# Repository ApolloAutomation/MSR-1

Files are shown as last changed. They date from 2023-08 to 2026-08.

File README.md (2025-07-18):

# Apollo mmWave CO2 Multisensor Mk1 (MSR-1)



This sensor offers a wide range of functionality for Home Assistant in a very tiny package.

YAML Files:
- MSR-1.yaml: This file is a minimal config. It doesn't have the bluetooth or OTA components. Use this if you are looking to add BLE proxy or BLE tracking.
- MSR-1_BLE.yaml: This file contains BLE proxy code. We use it as an automated test during our build process. But can be an example for adding BLE proxy to your device.
- MSR-1_Factory.yaml: This is the firmware flashed by us on new devices. It contains the components for ESP improve, allowing easy adoption in Home Assistant. When you load the device in ESPHome addon, it will grab the firmware from MSR-1.yaml which no longer has the improve.

Links: \
Discord (Support/feedback/discussion/future products): [https://dsc.gg/ApolloAutomation](https://dsc.gg/ApolloAutomation) \
Shop: [https://apolloautomation.com](https://apolloautomation.com) \
Wiki: [https://wiki.apolloautomation.com](https://wiki.apolloautomation.com/) \
3D Files: [https://www.printables.com/model/564297-apollo-automation-msr-1-mmwave-co2-multisensor-for](https://www.printables.com/model/564297-apollo-automation-msr-1-mmwave-co2-multisensor-for)

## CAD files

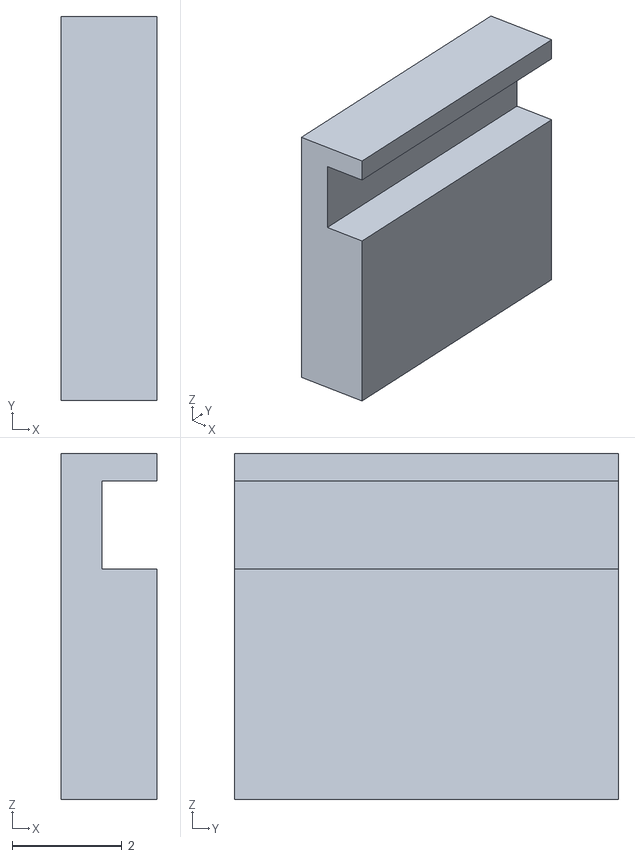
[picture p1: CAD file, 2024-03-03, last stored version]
3D Files/MSR-1_RadarMount_v4.stl
1.75 x 7.00 x 6.30

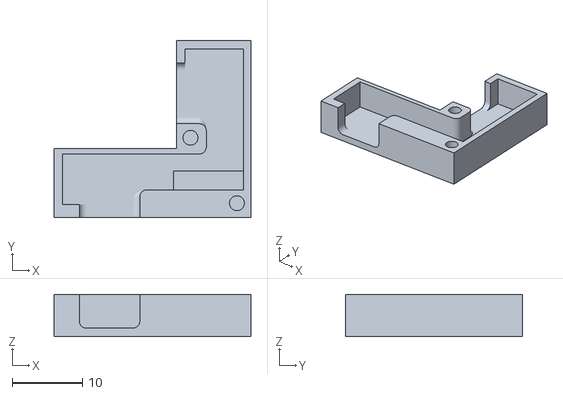
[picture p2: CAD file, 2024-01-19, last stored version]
3D Files/MSR-1_PlugCase_v33.stl
28.0 x 25.1 x 6.00

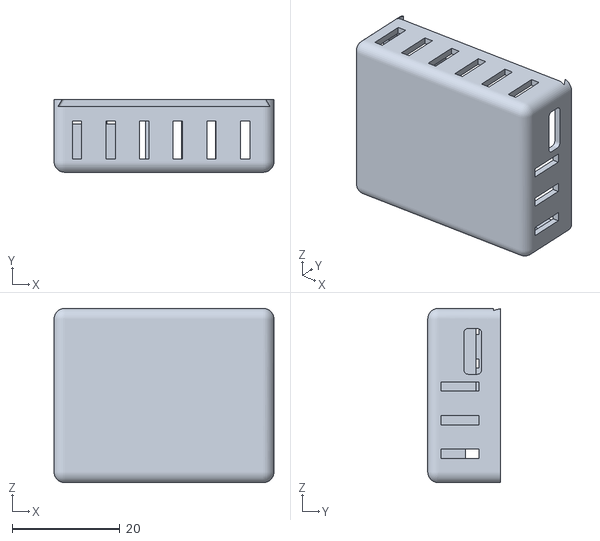
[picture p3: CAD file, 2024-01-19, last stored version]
3D Files/MSR-1_Case_v8.STL
40.9 x 13.5 x 32.4

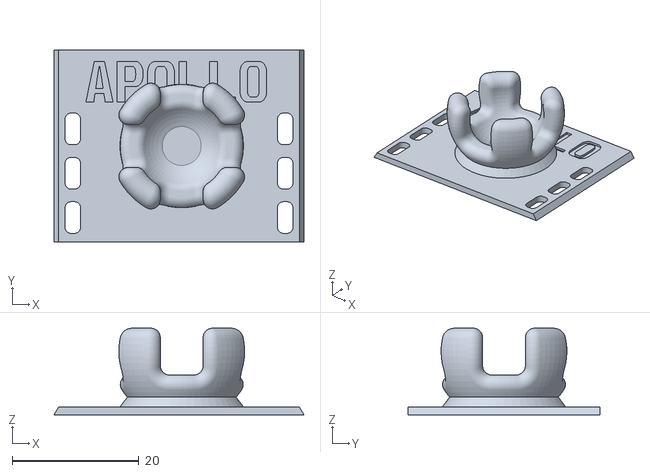
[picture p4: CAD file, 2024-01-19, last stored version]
3D Files/MSR-1_BallMount_Female_v3.STL
39.5 x 30.4 x 13.7

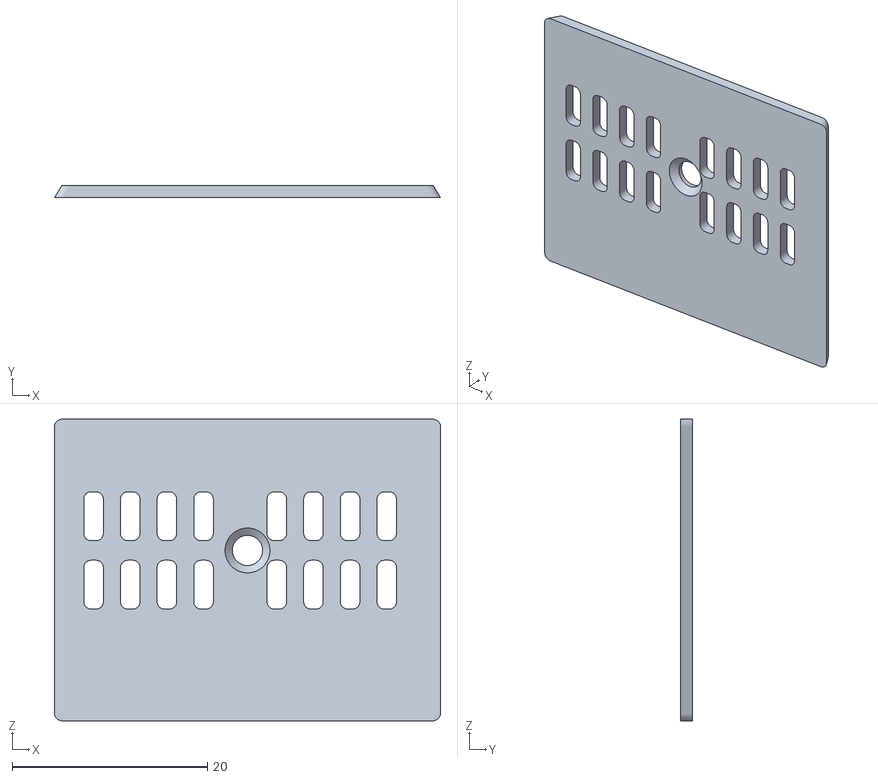
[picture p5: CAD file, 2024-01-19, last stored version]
3D Files/MSR-1_Backplate_v3.STL
39.5 x 1.25 x 30.9

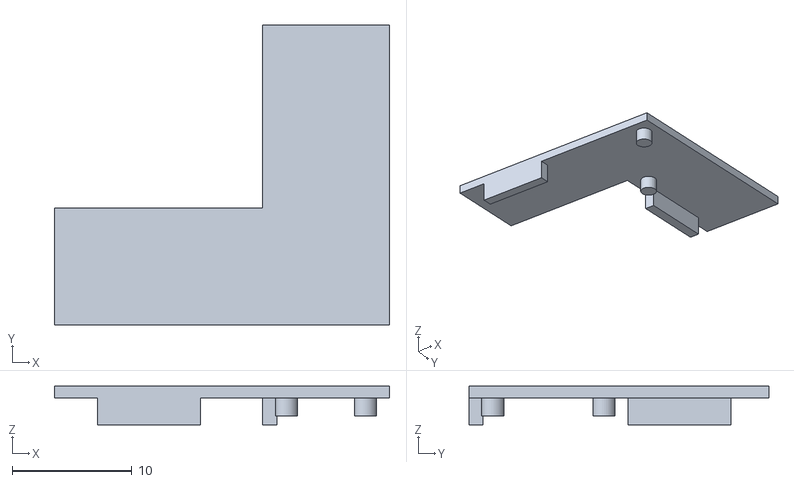
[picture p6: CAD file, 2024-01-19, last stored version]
3D Files/MSR-1_PlugCase_Cap_v33.stl
28.0 x 25.1 x 3.24

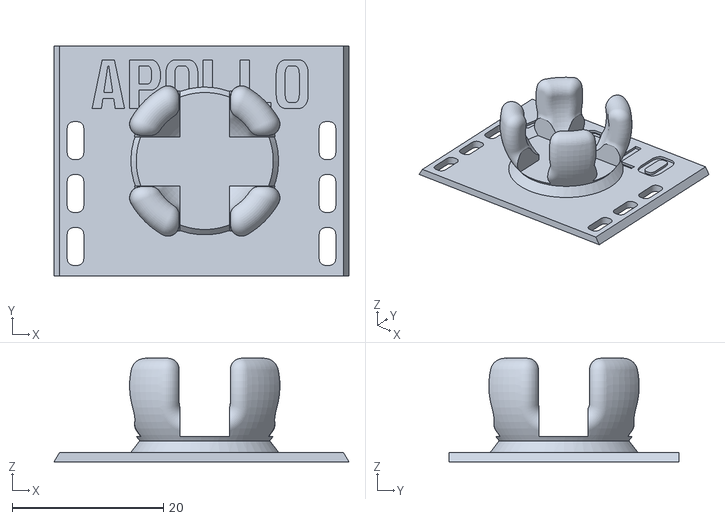
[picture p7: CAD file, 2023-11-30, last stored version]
3D Files/MSR-1_BallMount_Female_More_Rotation.STL
39.0 x 30.4 x 13.7

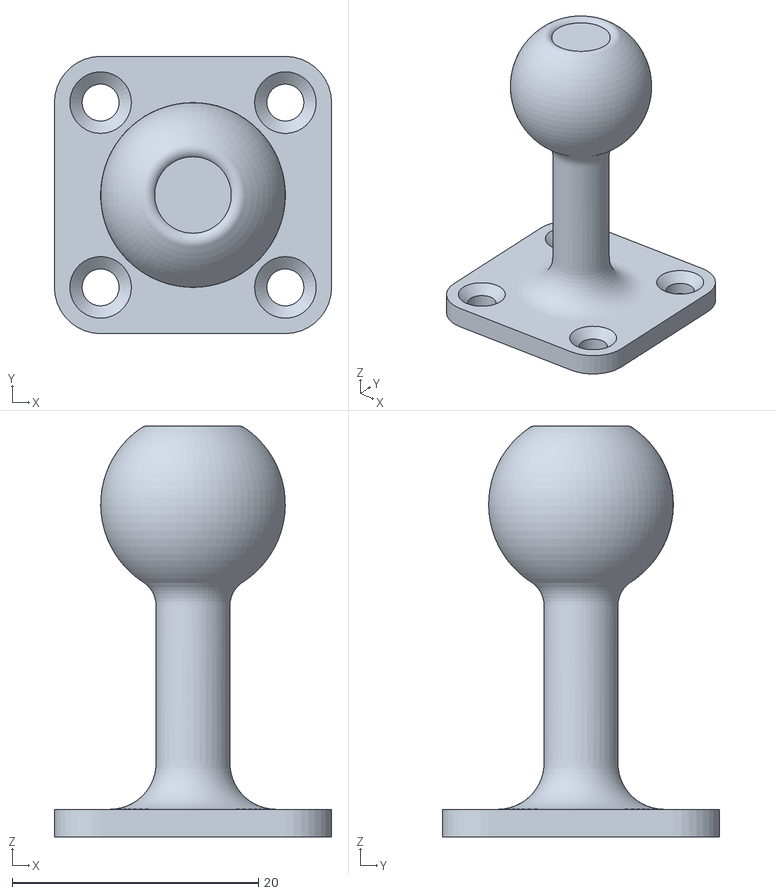
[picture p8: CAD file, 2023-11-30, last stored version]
3D Files/MSR-1_BallMount_Male_Long.STL
22.5 x 22.5 x 33.4

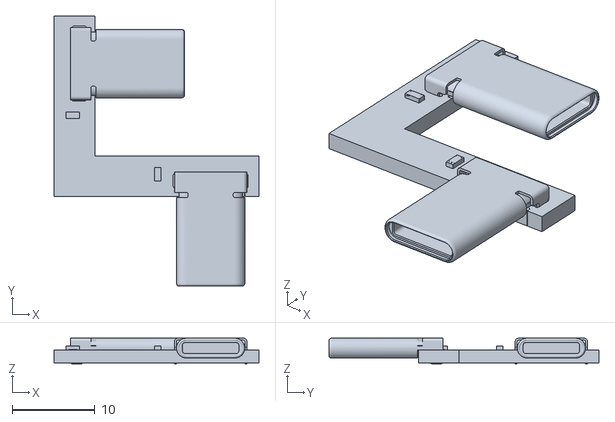
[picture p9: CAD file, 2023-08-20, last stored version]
3D Files/MSR-1_PlugMount.STL
24.7 x 32.6 x 3.10

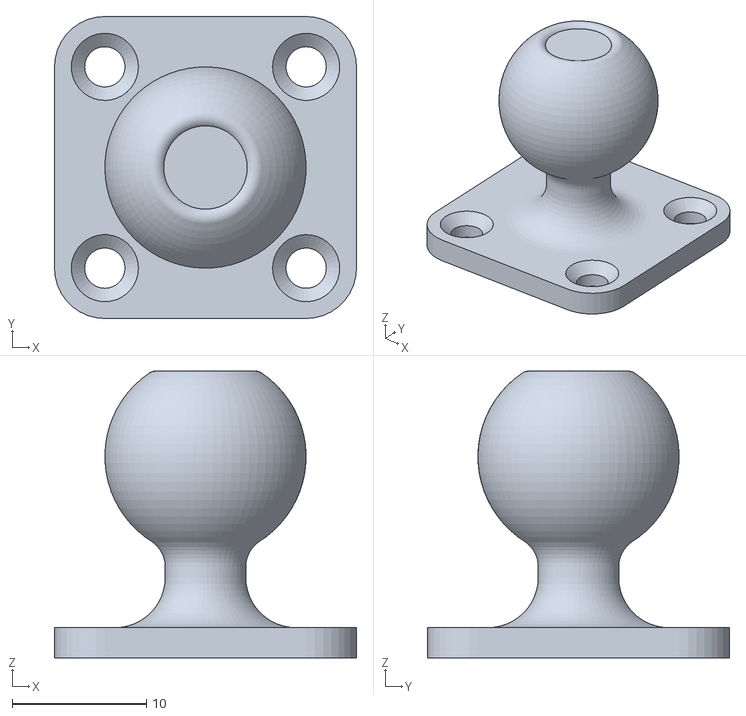
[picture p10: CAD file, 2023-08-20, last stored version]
3D Files/MSR-1_BallMountMale.STL
22.5 x 22.5 x 21.4

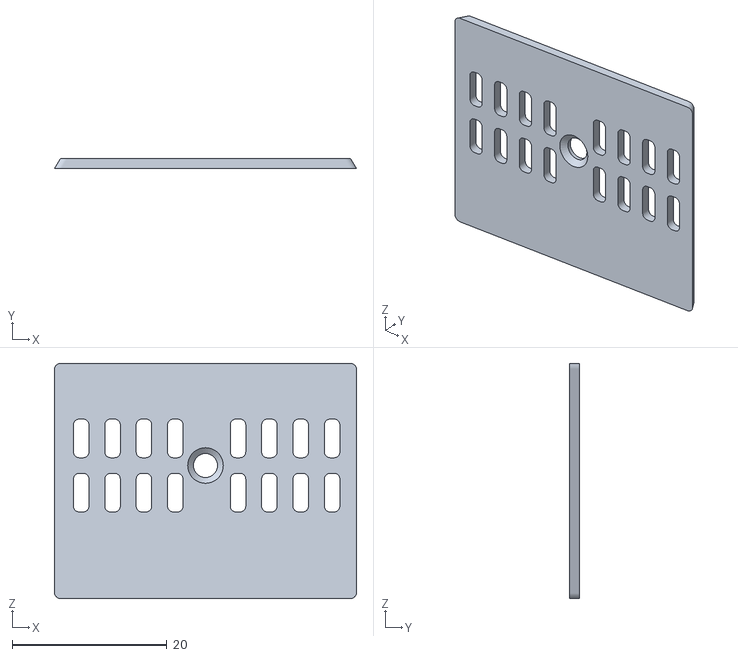
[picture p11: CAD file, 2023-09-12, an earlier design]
3D Files/MSR-1_Backplate.STL
39.0 x 1.25 x 30.4

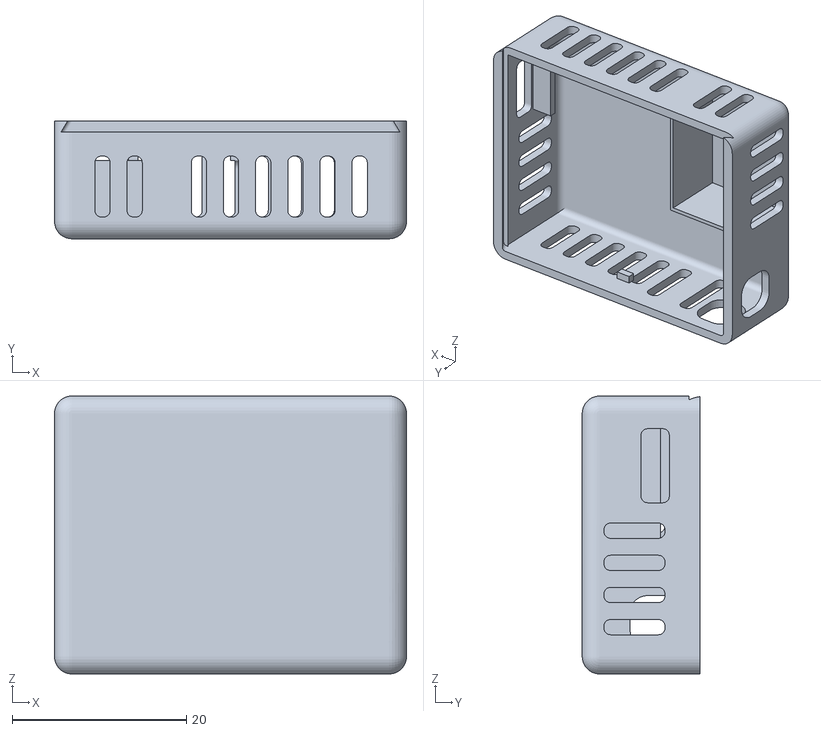
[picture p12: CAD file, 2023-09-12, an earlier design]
3D Files/MSR-1_Case_v6.STL
40.4 x 13.5 x 31.9

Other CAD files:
3D Files/MSR-1_PlugCaseCap.stl
3D Files/MSR-1_BallMountFemale.STL
3D Files/MSR-1_PlugCase.stl

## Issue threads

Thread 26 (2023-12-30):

ambient_light is using native unit of measurement '#' which is not a valid unit for the device class ('illuminance') it is using

morikplay, 2023-12-30:
**Core** 2023.12.4
**Supervisor** 2023.12.0
**Operating System** 11.2
**Frontend** 20231208.2

Getting a HA startup warning  after installation of 1st MSR-1

```
Logger: homeassistant.components.sensor
Source: components/sensor/__init__.py:691
Integration: Sensor (documentation, issues)
First occurred: 11:09:24 PM (3 occurrences)
Last logged: 11:09:24 PM

    Entity sensor.sensor_presence_mbr_ltr390_ambient_light (<class 'homeassistant.components.esphome.sensor.EsphomeSensor'>) is using native unit of measurement '#' which is not a valid unit for the device class ('illuminance') it is using; expected one of ['lx']; Please update your configuration if your entity is manually configured, otherwise create a bug report at https://github.com/home-assistant/core/issues?q=is%3Aopen+is%3Aissue+label%3A%22integration%3A+esphome%22
    Entity sensor.sensor_presence_mbr_ltr390_uv_index (<class 'homeassistant.components.esphome.sensor.EsphomeSensor'>) is using native unit of measurement 'UVI' which is not a valid unit for the device class ('illuminance') it is using; expected one of ['lx']; Please update your configuration if your entity is manually configured, otherwise create a bug report at https://github.com/home-assistant/core/issues?q=is%3Aopen+is%3Aissue+label%3A%22integration%3A+esphome%22
    Entity sensor.sensor_presence_mbr_ltr390_uv (<class 'homeassistant.components.esphome.sensor.EsphomeSensor'>) is using native unit of measurement '#' which is not a valid unit for the device class ('illuminance') it is using; expected one of ['lx']; Please update your configuration if your entity is manually configured, otherwise create a bug report at https://github.com/home-assistant/core/issues?q=is%3Aopen+is%3Aissue+label%3A%22integration%3A+esphome%22
```

relevant ESPHome config
```
substitutions:
  name: sensor-presence-mbr
  friendly_name: sensor-presence-mbr
packages:
  Apollo.Presence_Sensor: github://ApolloAutomation/MSR-1/Integrations/ESPHome/MSR-1.yaml
esphome:
  name: ${name}
  name_add_mac_suffix: false
  friendly_name: ${friendly_name}
```

Nunjafush, 2024-02-27:
Same problem for me with HA warnings at startup. Been happening for multiple versions of Core, OS and ESPHome since installed in early January 2024:

Core 2024.2.2
Supervisor 2024.02.0
Operating System 12.0
Frontend 20240207.1
ESPHome 2024.2.0

Log Details:

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

Relevant ESPHome config:

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

kuzaxak, 2024-03-20:
I think it happens because wrong sensor got exported. I see in ESPHome UI 3, but in HA only 2 of them.
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

Nunjafush, 2024-03-21:
The settings for LTR390 are apparently not defined in the Apollo MSR1 configuration but just read from the LTR390 definition in ESPHome.

In ESPHome, LTR390 had a device class of "illuminance" but yesterday's ESPHome 2024.3.0 update has now set it to "empty".
Since the update, I no longer get the errors in my log.

axx4one, 2024-03-25:
> In ESPHome, LTR390 had a device class of "illuminance" but yesterday's ESPHome 2024.3.0 update has now set it to "empty". Since the update, I no longer get the errors in my log.

I can confirm that the Light lux sensor is now gone (not just disabled) after updating to ESPHome 2024.3.0. That‘s not a fix but rather a new issue. My automations using the MSR-1 lux light sensor aren’t working anymore. The ambient light sensor cannot be used as well (e.g. in the Sensor Light blueprint from @Blacky).

neilmartin83, 2024-03-25:
Looks like we only have the `ambient_light` sensor for the LTR390 platform in https://github.com/ApolloAutomation/MSR-1/blob/789634b6d1ee802307523d167a15dbed01423654/Integrations/ESPHome/MSR-1.yaml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

I'd suggest replacing the `ambient_light` sensor with just `light` as not sure if we need it:

> ambient_light (Optional): [Sensor](https://esphome.io/components/sensor/#config-sensor) counts for the Ambient light sensor (#). All options from Sensor.

```
    light:
      name: "LTR390 Light"
      id: ltr390light
```

If you add the below to your own configuration YAML in the ESPHome addon and reflash, it will expose the correct sensor (I also set the `update_interval` every 5 seconds as it's much more useful for my use case):

```
sensor:
  - platform: ltr390
    id: !extend ltr_390
    light:
      name: "LTR390 Light"
      id: ltr390light
    update_interval: 5s
```

Bunton33, 2024-03-26:
We appreciate you sending us this update. I will talk with our technical
lead and see about implementing it. Please let us know if you need anything
else.

Best,
Justin Bunton
Apollo Automation

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

TrevorSchirmer, 2024-03-26:
Apologies for the mistake. When we reduce the firmware size I removed it on accident when I meant to remove ambient_light.

The PR is merged and should let you update from the ESPHome add-on in about a day.

Also sorry for not seeing the new comments on this issue, I'll figure out how to get better notifications from these. Feel free to tag me in the future if we break something.

Thanks for your all's help!

Thanks,
Trevor

cowboyrushforth, 2024-04-03:
Hey there, not sure if this is the best place to comment on this light sensor issue, but for me, I have two different MSR-1 units.

After this firmware update both show the light in HA - however, one unit is always "stuck" with whatever the light senses on bootup and never changes, the other one changes as the light level in the room changes.  For example if I shine a flashlight at it, it will correctly go way up to 120 lx, or if I turn off all the lights in the room it will go to 0 or 1 lx.

The other one works fine with regards to proximity and radar, but the light value again just stays at whatever it detects on bootup.  Is there a way to somehow hard reset that sensor?  I have tried reinstalling the firmware and power-cycling it but nothing seems to work.

Thanks!

TrevorSchirmer, 2024-04-03:
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

Hello,

Yes that seems to be some problem. I'm worried about notifying everyone on this thread with some troubleshooting back and forth. Can we move this to a new issue on GitHub? Or feel free to jump into our support channel on Discord and we can walk you through some steps and try to get it resolved. We can try to change the update interval, and look at the sensor's built in portal to see if it is a HA/network problem or a hardware problem.

Discord: https://discord.gg/mMNgQPyF94

Thanks!
-Trevor

Closed 2024-03-26.

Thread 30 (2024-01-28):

MSR-1 crashes/hangs several times a day

allthesebugsv2, 2024-01-28:
Hey there,

the sensor is unfortunately hanging several times a day. This goes hand in hand with a sharp increase in the esp temperature:

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

Usually, it restarts then at some point after becoming unavailable. But sometimes I even have to re-plug its power to make it available again. I have not noticed a pattern regarding this.

Firmware: 2023.11.6 (Dec 8 2023, 16:57:05)
Hardware: 23.12081

If there is a firmware update available, then I don't see where. I do not use ESPHome (only Home Assistant inside Docker), so I cannot follow this guide: https://wiki.apolloautomation.cloud/books/general/page/updating-firmware

Bunton33, 2024-01-28:
Hello,

Sorry to hear about the esp shutting down. There is a newer firmware
version. Can you try following this wiki guide?
https://wiki.apolloautomation.cloud/books/msr-1/page/manually-uploading-code-through-esphome

It uses ESPHome web so you shouldn't need the addon. Let us know how it
goes.

Thanks,
Justin Bunton
Apollo Automation

On Sun, Jan 28, 2024, 1:48 PM allthesebugsv2 ***@***.***>
wrote:

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

allthesebugsv2, 2024-01-30:
Thanks, I have managed to update the firmware and am now running
Firmware: 2023.11.6 (Jan 10 2024, 23:20:18)
Hardware: 24.1.10.1

However, even after updating I have had 3 crashes in the last 24h:
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

Bunton33, 2024-01-30:
Hello,

Glad to hear that you were able to update the firmware. We are not exactly
sure what's causing the device to crash though, so we will exchange it for
a new one. What is your order number?

Best,
Justin
Apollo Automation

On Tue, Jan 30, 2024, 7:47 AM allthesebugsv2 ***@***.***>
wrote:

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

allthesebugsv2, 2024-01-30:
That is extremely kind, I'll got back to you via mail

Closed 2024-01-30.

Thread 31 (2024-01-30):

Variables For Update Frequency

TrevorSchirmer, 2024-01-30:

KidA001, 2024-02-03:
Hey, thanks for creating this feature request. I'll paste my details from discord here:

One thing I would love is to change the update interval of the sensors as a variable (both for the distance sensor and air sensor). In order to do this currently I'd have to copy the ESPHome code and manually change it in there, which then means I have to manually maintain that code now and copy any updates manually.

Some of these sensors update very frequently which can be nice in some use cases, but ends up with a lot of granularity (and DB Writes) that I don't need. I'd love to be able to set the update interval with some kind of input variable. Much appreciated!

TrevorSchirmer, 2024-02-21:
@KidA001 Thank you very much for the addition here. I went back and forth but thought adding entities for all the sensors update frequency would clutter a little and confuse some.

Instead I made sure they all had IDs, this will allow you or anyone to !extend them and change the frequency. For example see attached, I changed the ltr390's update frequency from the default 60s to 5s. Please let me know if you have any questions or suggestions how to better handle this.

`sensor:
  - platform: ltr390
    id: !extend ltr_390
    update_interval: 5s`

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

-Trevor

Closed 2024-02-21.

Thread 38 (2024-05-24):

Wi-Fi power_save_mode set to “none”

neilmartin83, 2024-05-24:
Heya - this is more of a query than a problem.

I was wondering what the reasoning was for setting `power_save_mode: none`? Did you observe issues with the sensor or connectivity which needed this?

I tend to set this to `light` on all my ESP32 devices (it’s the default if not configured) and notice significantly lower running temps of the chip itself with no perceptible change of stability or performance.

Cheers! Loving this sensor.

Bunton33, 2024-05-24:
Neil,

We appreciate your support and thanks for reaching out! We debated this and decided to go with none because we didn't want people to experience any connectivity issues. If users talked about the heat buildup then we would suggests them to use light to decrease the heat. We haven't heard of or experienced any connectivity issues on any setting. The best part is it's all open source and the community can do whatever they want. Thanks again for the kind words. We are always available if you need anything.

Best,
Justin Bunton
Apollo Automation
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

TrevorSchirmer, 2024-05-25:
@neilmartin83 If you'd like help setting it to low power mode let us know and we can post a wiki article for it.
-Trevor

neilmartin83, 2024-05-25:
Cheers @TrevorSchirmer - I've already set it up on my MSR-1, as well as enabling Bluetooth proxy and disabling the web server, but think a KB would be great for others! It's been rock solid for weeks.

Thank you.

bharvey88, 2024-06-20:
solved wiki is now here https://wiki.apolloautomation.com/books/general/page/adjusting-wifi-power-save

Closed 2024-07-03.

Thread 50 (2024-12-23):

cannot change wifi

tung256, 2024-12-23:
anyone know how i can change my wifi?

as of now, everything works fine with my tmvc SSID.

i added tmvd to my house and hence this is my config.
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

when i click on Install Wirelessly, i get instant error. i also tried Update but same error :
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

when i tried to use ESPhome to compile this yaml  https://github.com/ApolloAutomation/MSR-1/blob/main/Integrations/ESPHome/MSR-1.yaml    i also get a bunch of errors:
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

can someone please help?

TrevorSchirmer, 2025-01-04:
Hello,

Sorry for the delay. It looks like your ESPHome addon version/integration might be too old? Can you update that and confirm if it is still happening.

Thanks,
Trevor

Closed 2025-02-20.

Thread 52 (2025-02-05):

MSR-1_BLE ESPHome install error - light.neopixelbus

stumain, 2025-02-05:
Trying to use the BLE enabled edition of the firmware for an MSR-1 but receive an error for light.neopixelbus in core.yaml.  Documentation on https://esphome.io/components/light/neopixelbus.html suggests this feature is not availble when using ESP-IDF.

Tried removing the use of the ESP-IDF and the firmware compile and install works.  Will wait and see how stable the MSR-1 using this.

Could be documentation update to remove the use of ESP-IDF or removal of neopixel functions if ESP-IDF is still required for another reason?

BTW, Awesome little sensors!!

neilmartin83, 2025-02-06:
If you are using ESP-IDF add this to your config in the ESPHome Builder to get the light working. esp32_rmt_led_strip is a replacement for neopixelbus.

```
light:
    platform: esp32_rmt_led_strip
    id: rgb_light
    name: RGB Light
    pin: GPIO3
    num_leds: 1
    rmt_channel: 0
    rgb_order: GRB
    chipset: ws2812
```

TrevorSchirmer, 2025-02-20:
Hi, apologies for the delay. There was a bug in the bluetooth yaml file we have but it wasn't the one you listed. I just merged a fix, could you give it a shot again?

Also could you link to the documentation that showed switching to ESP-IDF? I couldn't find it.

Thanks

TrevorSchirmer, 2025-07-18:
We just merged the firmware change to correct this and add new MSR-2 functionality to the MSR-1. Thanks again!

Closed 2025-03-27.

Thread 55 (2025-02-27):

Migrate from arduino framework to esp-idf

hajar97, 2025-02-27:
MSR-2 is already based on esp-idf framework. However, MSR-1 continues to stick to arduino. Since arduino has extra separation layers it can make the code run slower and device be more likely overloaded. ESPHome now recommends use of esp-idf framework as the main one. Can we migrate MSR-1 to this framework that is lighter and better supported in ESPHome?

RN-Say, 2025-07-18:
As of ESPHome version (2025.7.1) I am getting the following error that appears to be related to the arduino platform when attempting to install:

`INFO ESPHome 2025.7.1
INFO Reading configuration /config/esphome/apollo-msr-1-06dbc0.yaml...
INFO Updating https://github.com/ApolloAutomation/MSR-1@main
INFO Generating C++ source...
INFO Compiling app...
Processing guest-bath-multisensor (board: esp32-c3-devkitm-1; framework: arduino; platform: https://github.com/pioarduino/platform-espressif32/releases/download/53.03.13/platform-espressif32.zip)
--------------------------------------------------------------------------------
Library Manager: Installing SPI
INFO Installing SPI
HARDWARE: ESP32C3 160MHz, 320KB RAM, 4MB Flash
 - framework-arduinoespressif32 @ 3.1.3
 - framework-arduinoespressif32-libs @ 5.3.0+sha.489d7a2b3a
 - tool-esptoolpy @ 4.8.6
 - tool-mklittlefs @ 3.2.0
 - tool-riscv32-esp-elf-gdb @ 14.2.0+20240403
 - tool-xtensa-esp-elf-gdb @ 14.2.0+20240403
 - toolchain-riscv32-esp @ 13.2.0+20240530
Dependency Graph
|-- Networking @ 3.1.3
|-- AsyncTCP @ 3.4.5
|-- WiFi @ 3.1.3
|-- FS @ 3.1.3
|-- Update @ 3.1.3
|-- ESPAsyncWebServer @ 3.7.10
|-- ESP32 Async UDP @ 3.1.3
|-- DNSServer @ 3.1.3
|-- ESPmDNS @ 3.1.3
|-- Wire @ 3.1.3
|-- ArduinoJson @ 7.4.2
|-- NeoPixelBus @ 2.8.0
|-- noise-c @ 0.1.10
RAM:   [==        ]  19.0% (used 62244 bytes from 327680 bytes)
Flash: [==========]  114.1% (used 2094434 bytes from 1835008 bytes)
Error: The program size (2094434 bytes) is greater than maximum allowed (1835008 bytes)

💡 TIP: Your ESP32 with Arduino framework has run out of flash space.

To fix this, switch to the ESP-IDF framework which is more memory efficient:

1. In your YAML configuration, modify the framework section:

   esp32:
     framework:
       type: esp-idf

2. Clean build files and compile again

Note: ESP-IDF uses less flash space and provides better performance.
Some Arduino-specific libraries may need alternatives.

*** [checkprogsize] Explicit exit, status 1
========================== [FAILED] Took 4.62 seconds ==========================`

Closed 2025-07-18.

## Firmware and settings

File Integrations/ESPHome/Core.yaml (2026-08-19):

substitutions:
  version:  "26.8.19.1"
  device_description: ${name} made by Apollo Automation - version ${version}.
  # Default OTA password. Override in your device YAML by re-declaring
  # `substitutions: { ota_password: !secret <name>_ota_password }` so each
  # device on your network uses a unique secret instead of the shared default.
  ota_password: "apolloautomation"
  # Manifest URL bases. Stable = GitHub Pages (main branch builds).
  # Beta = rolling "beta" pre-release assets (beta branch builds).
  stable_manifest_base: "https://apolloautomation.github.io/MSR-1"
  beta_manifest_base: "https://github.com/ApolloAutomation/MSR-1/releases/download/beta-fw"
  # Per-variant OTA manifest URLs. Core defaults to the unified (standard)
  # image; MSR-1_BLE.yaml overrides these so legacy BLE devices stay on the
  # firmware-ble manifest.
  ota_stable_manifest: "${stable_manifest_base}/firmware/manifest.json"
  ota_beta_manifest: "${beta_manifest_base}/manifest-standard.json"

  # Bluetooth Proxy switch state on a device with no stored preference yet
  # (first boot after this switch was added, or after a factory reset). The
  # unified image ships the proxy off; MSR-1_BLE.yaml overrides this to ON so
  # legacy BLE devices keep proxying instead of going quiet after an update.
  bluetooth_proxy_restore_mode: RESTORE_DEFAULT_OFF

esphome:
  # List form so package merging concatenates with each variant's own on_boot
  # entries (mapping form would be replaced by the variant's block instead).
  on_boot:
    - priority: -100
      then:
        - script.execute: apply_ota_source
    # Re-apply the Bluetooth Proxy switch after all components set up, so BLE
    # scanning matches the switch state restored from flash.
    - priority: -300
      then:
        - if:
            condition:
              switch.is_on: bluetooth_proxy_switch
            then:
              - esp32_ble_tracker.start_scan:
                  continuous: true
            else:
              - esp32_ble_tracker.stop_scan:

esp32:
  variant: esp32c3
  flash_size: 4MB
  framework:
    type: esp-idf

esp32_ble_tracker:
  id: ble_tracker
  scan_parameters:
    continuous: true

bluetooth_proxy:

captive_portal:

web_server:
  port: 80
  version: 3

http_request:
  verify_ssl: true
  # GitHub release-asset downloads answer with a redirect carrying a
  # ~3.6 KB Content-Security-Policy header; each header line must fit
  # this buffer or the request fails with "HTTP_CLIENT: Out of buffer".
  buffer_size_rx: 5120
  # The redirect target is a signed URL with a ~850-char query string; the
  # follow-up request line must fit the TX buffer or esp_http_client_open
  # fails with "Out of buffer" before sending anything.
  buffer_size_tx: 2048

api:
  encryption:
  on_client_connected:
    - delay: 1s
    - light.turn_off: rgb_light
    - lambda: 'id(cycleCounter) = 30;'
  actions:
    - action: play_buzzer
      variables:
        song_str: string
      then:
        - rtttl.play:
            rtttl: !lambda 'return song_str;'

    #Co2 Calibration Action
    - action: calibrate_co2_value
      variables:
        co2_ppm: float
      then:
        - scd4x.perform_forced_calibration:
            value: !lambda 'return co2_ppm;'
            id: scd40

    #Setting HLK Password
    - action: set_ld2410_bluetooth_password
      variables:
        password: string
      then:
        - bluetooth_password.set:
            id: ld2410_radar
            password: !lambda 'return password;'

globals:
  - id: cycleCounter
    type: int
    restore_value: no
    initial_value: '0'
  - id: button_press_timestamp
    restore_value: no
    type: uint32_t
    initial_value: '0'
  - id: ltr390_last_update
    restore_value: no
    type: uint32_t
    initial_value: '0'

i2c:
  sda: GPIO1
  scl: GPIO0
  id: bus_a

uart:
  tx_pin: GPIO21
  rx_pin: GPIO20
  baud_rate: 256000
  parity: NONE
  stop_bits: 1
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

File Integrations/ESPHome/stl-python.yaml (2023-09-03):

#Define Project
substitutions:
  name: apollo-msr-1
  version:  23-08-26-1
  device_description: ${name} made by ApolloAutomation - version ${version}.
  
esphome:
  name: "${name}"
  friendly_name: Apollo Multisensor Mk1 (MSR-1)
  comment: Apollo Multisensor Mk1 (MSR-1)
  name_add_mac_suffix: true
  platformio_options:
    board_build.flash_mode: dio

  on_boot:
  - priority: 900.0
    then:
      - lambda: |-
          id(cpu_speed) = ESP.getCpuFreqMHz();

  #- priority: 250
  #  then:
  #    - delay: 15s
  #    - lambda: |-
  #        id(ble_tracker).set_scan_continuous(true);
  #        id(ble_tracker).start_scan();

  project:
    name: "ApolloAutomation.MSR-1"
    version: "MSR-1"

  min_version: 2023.8.1 #2023.6.1

# Define Board
esp32:
  board: esp32-c3-devkitm-1
  framework:
    type: arduino
  #board: featheresp32-s2
  
dashboard_import:
  package_import_url: github://ApolloAutomation/MSR-1/Integrations/ESPHome/stl-python.yaml

globals:
  - id: cpu_speed
    type: int
    restore_value: no
    initial_value: "0"

# Enable Home Assistant API
# Also Add Buzzer Service Connection
api:

  services:
    - service: play_buzzer
      variables:
        song_str: string
      then:
        - rtttl.play:
            rtttl: !lambda 'return song_str;'

    #Co2 Calibration Service
    - service: calibrate_co2_value
      variables:
        co2_ppm: float
      then:
        - scd4x.perform_forced_calibration:
            value: !lambda 'return co2_ppm;'
            id: scd40

    #Setting HLK Password
    - service: set_ld2410_bluetooth_password
      variables:
        password: string
      then:
        - bluetooth_password.set:
            id: ld2410_radar
            password: !lambda 'return password;'

logger:

ota:
  password: "apolloautomation"
  safe_mode: false

wifi:

  power_save_mode: none

  # Enable fallback hotspot (captive portal) in case wifi connection fails
  ap:
    ssid: "Apollo MSR1 Hotspot"

captive_portal:

improv_serial:

web_server:
  port: 80

#esp32_ble_tracker:
#  id: ble_tracker
#  continuous_mode: false
#  interval: 211ms
#  window: 120ms



# Set Up Key Ports For Communication
i2c:
  sda: GPIO1
  scl: GPIO0
  id: bus_a

uart:
  tx_pin: GPIO21
  rx_pin: GPIO20
  baud_rate: 256000
  parity: NONE
  stop_bits: 1

# Numbers For Configuration
number:
  - platform: ld2410
    timeout:
      name: Radar Timeout
    max_move_distance_gate:
      name: Radar Max Move Distance
    max_still_distance_gate:
      name: Radar Max Still Distance
    g0:
      move_threshold:
        name: g0 move threshold
      still_threshold:
        name: g0 still threshold
    g1:
      move_threshold:
        name: g1 move threshold
      still_threshold:
        name: g1 still threshold
    g2:
      move_threshold:
        name: g2 move threshold
      still_threshold:
        name: g2 still threshold
    g3:
      move_threshold:
        name: g3 move threshold
      still_threshold:
        name: g3 still threshold
    g4:
      move_threshold:
        name: g4 move threshold
      still_threshold:
        name: g4 still threshold
    g5:
      move_threshold:
        name: g5 move threshold
      still_threshold:
        name: g5 still threshold
    g6:
      move_threshold:
        name: g6 move threshold
      still_threshold:
        name: g6 still threshold
    g7:
      move_threshold:
        name: g7 move threshold
      still_threshold:
        name: g7 still threshold
    g8:
      move_threshold:
        name: g8 move threshold
      still_threshold:
        name: g8 still threshold

  #Temperature Offsets
  - platform: template
    name: SCD40 Temperature Offset
    id: scd40_temperature_offset
    restore_value: true
    initial_value: 20.0
    min_value: -70.0
    max_value: 70.0
    entity_category: "CONFIG"
    unit_of_measurement: "°"
    optimistic: true
    update_interval: never
    step: 0.1

  - platform: template
    name: BME280 Temperature Offset
    id: bme280_temperature_offset
    restore_value: true
    initial_value: 20.0
    min_value: -70.0
    max_value: 70.0
    entity_category: "CONFIG"
    unit_of_measurement: "°"
    optimistic: true
    update_interval: never
    step: 0.1

  - platform: template
    name: Co2 Calibration Number
    id: co2_calibration_number
    restore_value: true
    initial_value: 419.0
    min_value: 0.0
    max_value: 1000.0
    entity_category: "CONFIG"
    unit_of_measurement: "ppm"
    optimistic: true
    mode: "box"
    update_interval: never
    step: 10
    set_action:
      - scd4x.perform_forced_calibration:
          value: !lambda 'return id(co2_calibration_number).state;'
          id: scd40

# Buzzer
output:
  - platform: ledc
    pin: GPIO10
    id: buzzer
rtttl:
 output: buzzer
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

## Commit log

2023-08-27 Update Case For Better Printing
    Updated the lip at top of case where wall was too thin.
    [MSR-1_Backplate.STL, MSR-1_BallMountFemale.STL, MSR-1_BallMountMale.STL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]
2023-09-03 Update stl-python.yaml
    remove secret keys
    ad improv_serial:
2023-09-04 Remove Device Class
2023-09-05 Auto Turn Off Radar, Add Device Class
2023-09-11 Updated 3D Design
    [MSR-1_Backplate.STL, MSR-1_BallMountFemale.STL, MSR-1_Case.STL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]
2023-09-16 Switch To Green Theme
2023-09-24 Add LED/Buzzer
2023-11-02 Remove Some Of The Temperature Confusion
2023-11-30 Added Ball Mount Version With More Movement
    [MSR-1_BallMount_Female_More_Rotation.STL, MSR-1_BallMount_Male_Long.STL]
2023-12-11 Adding IDs To Sensors
2023-12-18 Allow Controlling Startup LED
2024-01-07 Moved Calibrate Temperature To Button. Moved Internal Temp To Diag
2024-01-19 Updated 3D Models
    [MSR-1_Backplate_v3.STL, MSR-1_BallMount_Female_v3.STL, MSR-1_Case_v8.STL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]
2024-03-26 Add Back The Correct Light Sensor
2024-07-03 Managed Update, Improv, Action
    [MSR-1_Backplate.STL, MSR-1_Backplate_v3.STL, MSR-1_BallMountFemale.STL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]
2024-07-05 Remove Power Save On BLE Script
2024-07-05 Ignore Strapping Pin
2025-02-20 Light Effects And Fix Version
    [Core.yaml]
2025-02-28 Switch To IDF And Combine YAML
2025-07-19 Fixed number of LEDs to 1
    1. Existing code has MSR-1 as having 3 LEDs in the strip. Corrected this to 1.
    2. Proposing a default rmt_symbols value of 48. This is not strictly needed, but helps anyone adding a second LED strip from having to extend the "RGB Light" entity. 48 is the only real choice due to ESP32-C3's limit of 92 symbols, assignable in 48-symbol chunks (so it might as well be a default, as adding another RMT LED would require that one to be 48 as well).
    [Core.yaml]
2025-08-06 CI Fix
    Fixed firmware building
    [Core.yaml]
2026-05-18 chore(esphome): parameterize OTA password (preserve current default)
    Promote the hardcoded `password: "apolloautomation"` literal in
    `MSR-1.yaml` and `MSR-1_BLE.yaml` to a `${ota_password}` substitution
    defined in `Core.yaml`, defaulting to the same value. Existing consumers
    see no behavior change. Consumers who include this file via `packages:`
    can override per-device via their own `substitutions:` block.
2026-06-11 Add HTTP request OTA update system from R_PRO-1
    Port the managed firmware update system from R_PRO-1 to all MSR-1
    variants:
    - Add http_request OTA platform alongside the existing esphome OTA
    - Add update component pulling the firmware manifest from GitHub Pages
    - Add safe_mode for recovery from failed updates
    - Build and publish the BLE variant (firmware-ble) so BLE devices
    update from their own manifest instead of being converted to the
    factory firmware
2026-06-11 Check for updates when WiFi connects
    The http_request update component polls every 6h and the first poll
    fires before the network is up, so a freshly booted device would not
    see an available update for 6 hours. Trigger a manifest check as soon
    as WiFi connects.
2026-07-07 Add Firmware Channel switching from HA
    Same Stable/Beta channel switching as CAST-1 (ApolloAutomation/CAST-1#43
    naming):
    - Firmware Channel select (Stable/Beta) sets the OTA manifest URL via a
    new apply_ota_source script; each image tracks its own variant's
    manifests through the ble_firmware substitution.
    - Firmware Update button force-installs the selected channel's firmware.
    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
2026-07-08 Rename rolling beta release tag to beta-fw (branch/tag collision)
    The rolling pre-release created a tag named "beta", colliding with the
    beta branch. git resolves a bare fetch refspec to refs/tags/ before
    refs/heads/, so ESPHome remote packages pinned to ref: beta silently
    fetch the tag (which pointed at main's HEAD at creation and never
    moves) instead of the branch tip - users following beta as a package
    get stale YAML no matter how often they clean caches.
    Rename the release tag to beta-fw and update beta_manifest_base to
    match. The old beta release/tag should be deleted after this merges
    and the renamed release is populated.
    Version: 26.7.8.2 (26.7.8.1 is reserved by the open Bluetooth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
    [Core.yaml]
2026-07-08 Add Bluetooth Proxy firmware switching from HA
    Second half of the AIR-1 #107 split: lets users swap between the
    standard and Bluetooth-proxy images from HA instead of reflashing over
    USB or editing YAML.
    - Bluetooth Proxy select (Disabled/Enabled) joins Firmware Channel in
    composing the OTA manifest URL via apply_ota_source.
    - On boot each image publishes its real identity into the select
    (ble_firmware substitution), so a failed or abandoned switch snaps
    back to the truth.
    - Same-version variant switches install via the existing Firmware
    Update force button (merged in #89), which already frees heap by
    disabling BLE during the download.
    No workflow changes: build-beta.yml and Page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
    [Core.yaml]
2026-07-08 Fix beta manifest fetch and guard force-install against stale manifests
    Hardware testing surfaced two OTA bugs (thanks Brandon):
    - GitHub release-asset URLs answer with a redirect whose signed Location
    header exceeds esp_http_client's 512-byte default rx buffer, so every
    beta-channel manifest fetch failed with "HTTP_CLIENT: Out of buffer".
    Set buffer_size_rx: 2048 on all images.
    - update.perform(force) installs whatever manifest was last fetched
    successfully. Combined with the fetch failure above, pressing
    Firmware Update on the Beta channel silently installed the cached
    STABLE manifest - downgrading the device to the old image (which
    also wiped its saved settings, including W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
    [Core.yaml]
2026-07-08 Raise http_request rx buffer to 5120 for GitHub's CSP header
    The redirect on release-asset downloads carries a ~3.6 KB
    Content-Security-Policy header line; esp_http_client requires each
    header line to fit the rx buffer, so 2048 still failed with
    "HTTP_CLIENT: Out of buffer" (confirmed on hardware running 26.7.8.6;
    the new manifest guard correctly refused to install, so no downgrade).
    Version: 26.7.8.7
    [Core.yaml]
2026-07-08 Set http_request buffer_size_tx: 2048 - the real Out of buffer fix
    IDF's esp_http_client emits "Out of buffer" from request-line
    composition: GET <path>?<query> must fit buffer_size_tx. GitHub's
    release-asset redirect points at a signed URL with a ~850-char query
    string, so the follow-up request could never be built in the 512-byte
    default TX buffer - this is why esp_http_client_open failed, and why
    raising the RX buffer (#93, #94) didn't help. Confirmed against the
    IDF source (esp_http_client.c, http_client_prepare_first_line).
    Version: 26.7.8.8
    [Core.yaml]
2026-07-09 Unify BLE into one firmware: runtime Bluetooth Proxy switch + channel-only OTA
    Replaces the build-time BLE variant machinery with runtime toggles:
    - Compile bluetooth_proxy + esp32_ble_tracker into Core.yaml so every variant
    inherits it (base ~94.1% flash, Factory ~95.4% - both fit 4MB).
    - Add a "Bluetooth Proxy" switch (default off) that starts/stops scanning via
    esp32_ble_tracker; the esp32_ble stack stays up so esp32_improv keeps working
    on the Factory image.
    - Remove the firmware_ble manifest selector. apply_ota_source is now
    channel-only, using per-variant manifest bases (ota_stable_manifest /
    ota_beta_manifest) so legacy MSR-1_BLE devices keep their firmware-ble manifest.
    - D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
    [Core.yaml]
2026-07-09 Remove vestigial ble_firmware substitution; fix build.yml device-name
    The ble_firmware substitution is no longer read by anything after the
    runtime Bluetooth Proxy switch replaced the firmware_ble manifest selector
    (#100) - remove it from Core.yaml and MSR-1_BLE.yaml. Also correct the
    copy-pasted device-name input in build.yml (msr-2 -> msr-1); it is a
    required-but-unused input in the shared workflow, so this is a no-op
    correctness fix.
    No compiled-output change; does not publish.
    [Core.yaml]
2026-07-09 Drop redundant bluetooth_proxy active: true
    The bluetooth_proxy component now enables active connections by default,
    and Home Assistant manages active-vs-passive dynamically - it opens an
    active connection only when an integration needs one, staying passive
    otherwise. So the explicit active: true is redundant with the current
    default. Dropping it leaves the bare bluetooth_proxy: line with identical
    behavior/compiled output.
    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
2026-07-14 Add heartbeat floor to Reduce DB Reporting ambient sensors
    The reduce-gated ambient sensors (ESP temp, LTR390 light/UV) used a
    hardcoded delta with no time floor, so with Reduce DB Reporting on they
    could freeze and never show a value on boot.
    Give them a delta-OR-hourly-heartbeat floor and publish the first
    post-boot reading. Radar filters, BME280 pressure, and the toggle-off
    path are unchanged.
    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
2026-07-24 Re-point beta-fw tag on every beta publish
    The rolling beta-fw release tag stays on the commit that was default-branch
    HEAD when the release was first created. gh release create without --target
    tags default-branch HEAD, and gh release upload never moves the tag, so the
    published assets track every beta build while the release source commit does
    not.
    Add a step to build-beta.yml that PATCHes the beta-fw tag ref to the built
    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
2026-07-29 Keep Bluetooth Proxy on for legacy BLE builds
    The Bluetooth Proxy switch does restore from flash, but the _OFF half of
    RESTORE_DEFAULT_OFF decides the boot where nothing is stored yet, which is
    the first boot after the switch shipped. MSR-1_BLE.yaml inherited that mode
    from Core, so legacy BLE devices that had always proxied came up with the
    proxy off after updating.
    Core now reads the mode from a bluetooth_proxy_restore_mode substitution
    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
2026-08-19 Publish on NAN state transitions instead of whenever last value was NAN
    The isnan(last_reported_value) first-publish check had two failure modes
    once a sensor read produced NAN: the failure was hidden until the hourly
    heartbeat, and after the heartbeat published NAN every subsequent reading
    bypassed the delta filter, reverting the sensor to full-rate reporting.
    Use last_report_time == 0 as the first-publish check and publish
    immediately when the reading transitions into or out of NAN, in all three
    Reduce DB Reporting lambdas. Also merges beta (version now 26.8.19.1).
    [Core.yaml]
2026-08-28 Replace deprecated rgb_order with channel_colors
    ESPHome 2026.8.0 replaces rgb_order/is_rgbw/is_wrgb with a single
    channel_colors key on esp32_rmt_led_strip (esphome#18474).
    [Core.yaml]
2026-08-30 Require ESPHome 2026.8.0 for channel_colors
    `channel_colors` only exists from ESPHome 2026.8.0 (esphome#18474), but
    these YAMLs still declared an older min_version. Devices adopted through
    the ESPHome dashboard track this repo at HEAD with no pinned ref, so on
    an older ESPHome the next recompile fails with "Unknown option
    channel_colors" pointing into a file the user never wrote, instead of a
    clear version error.
    ESPHome merges remote packages and checks min_version in the preload
    phase, before component schemas load, so the bump produces the right
    message. No firmware change: min_version is validation-only and emits no
    code, so the compiled binary is unaffected.
    🤖 Generated with [Claud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
2026-09-29 Fix OTA manifest lambda for ESPHome dev
    [Core.yaml]
2026-10-07 Add id to ESPHome OTA block so package users can enable OTA encryption
    Give the `platform: esphome` OTA entry in MSR-1.yaml and MSR-1_BLE.yaml
    the id `ota_default` (same as MSR-2.yaml). Device configs that include
    these files via `packages:` can then switch to encrypted OTA with
    `!extend ota_default`, `password: !remove` and `encryption:`. ESPHome
    rejects `password` together with `encryption`, and without an id the
    packaged password cannot be removed.
    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
